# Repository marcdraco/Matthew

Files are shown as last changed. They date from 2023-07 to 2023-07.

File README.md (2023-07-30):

# Matthew
High-performance headphone amplifier based on the NE5532DR

This is, I hope the last main revision for this project (third one is a charm) after I found I'd specificied the wrong value on the JLCPCB ordering page resulting in 100K resistors being replaced by 1 ohm ... and the Magic Smoke came without the genie... Oh well. This is why I ask everyone to wait until I've gotten final boards back and tested them before you spend your money on my mistakes. I wish I never made a mistake but you know, it's how we learn.

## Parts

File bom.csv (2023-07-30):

Designator | Footprint | Quantity | Value | LCSC Part #
C101, C102, C103, C104 | C_Elec_10x10.2 | 4 | 1000u | C3359
C105, C106, C107, C108, C109, C110, C111, C112 | 0603 | 8 | 100n | C14663
C113, C114 | 1206 | 2 | 22u | C12891
C115, C116 | C_Elec_8x10.2 | 2 | 470U | C2827943
J1, J102 | PinHeader_1x03_P2.54mm_Vertical | 2 | Conn_01x03 | DNP
J104 | PinHeader_1x02_P2.54mm_Vertical | 1 | Socket_01x02 | DNP
R101, R102, R103, R104, R105, R106, R107, R108, R109, R110, R111, R112, R113, R114, R115, R116 | 0805 | 16 | 10R | C17415
R117, R118, R119, R120 | 0603 | 4 | 100K | C25803
U101, U102, U103, U104, U105, U106, U107, U108, U109 | SOIC-8_3.9x4.9mm_P1.27mm | 9 | NE5532 | C7426

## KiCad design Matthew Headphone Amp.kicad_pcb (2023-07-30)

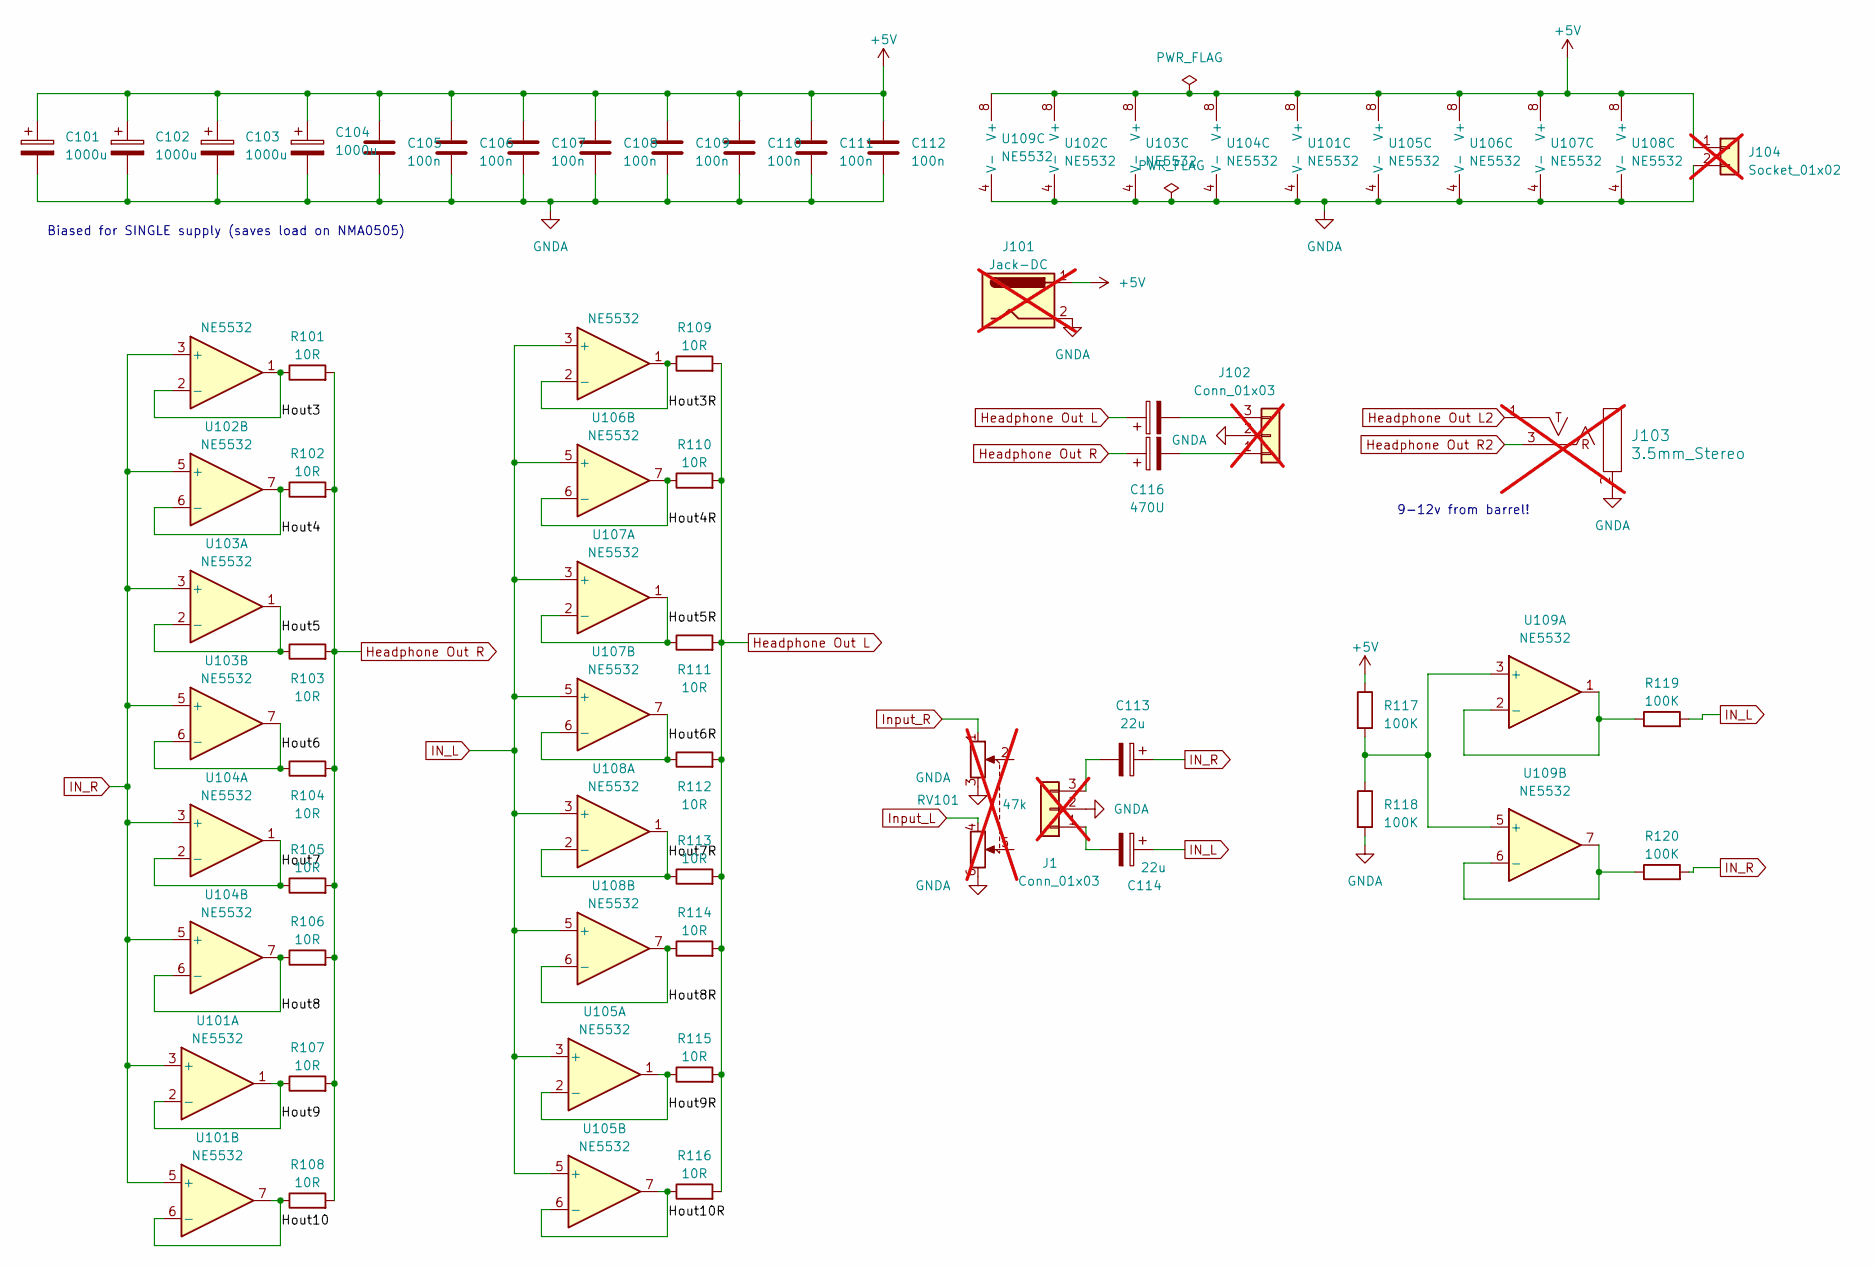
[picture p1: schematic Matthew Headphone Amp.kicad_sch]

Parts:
C101, C102, C103, C104: 1000u; C_Elec_10x10.2; MPN C3359
C105, C106, C107, C108, C109, C110, C111, C112: 100n; C_0603_1608Metric; MPN C14663
C113: 22u; C_1206_3216Metric; MPN C12891
C114: 22u; C_1206_3216Metric; MPN C12891; JLCPCBPart# C1289
C115, C116: 470U; C_Elec_8x10.2; MPN C2827943
J1, J102: Conn_01x03; PinHeader_1x03_P2.54mm_Vertical; Part Number 1-0301FBV0T; not fitted
J101: Jack-DC; PinHeader_1x02_P2.54mm_Vertical; not fitted
J103: 3.5mm_Stereo; EighthInch_Stereo_PJ366ST; Part Number WQP-WQP419GR; not fitted
J104: Socket_01x02; PinHeader_1x02_P2.54mm_Vertical; Part Number ?; not fitted
R101, R102, R103, R104, R105, R106, R107, R108, R109, R110, R111, R112, R113, R114, R115, R116: 10R; R_0805_2012Metric; MPN C17415
R117, R118, R119, R120: 100K; R_0603_1608Metric; MPN C25803
RV101: 47k; not fitted
U101, U102, U103, U104, U105, U106, U107, U108, U109: NE5532; SOIC-8_3.9x4.9mm_P1.27mm; MPN C7426

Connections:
+5V: C101.1, C102.1, C103.1, C104.1, C105.1, C106.1, C107.1, C108.1, C109.1, C110.1, C111.1, C112.1, J101.1, J104.1, R117.1, U101.8 (V+), U102.8 (V+), U103.8 (V+), U104.8 (V+), U105.8 (V+), U106.8 (V+), U107.8 (V+), U108.8 (V+), U109.8 (V+)
/Hout3: R101.1, U102.1, U102.2 (-)
/Hout3R: R109.1, U106.1, U106.2 (-)
/Hout4: R102.1, U102.6 (-), U102.7
/Hout4R: R110.1, U106.6 (-), U106.7
/Hout5: R103.1, U103.1, U103.2 (-)
/Hout5R: R111.1, U107.1, U107.2 (-)
/Hout6: R104.1, U103.6 (-), U103.7
/Hout6R: R112.1, U107.6 (-), U107.7
/Hout7: R105.1, U104.1, U104.2 (-)
/Hout7R: R113.1, U108.1, U108.2 (-)
/Hout8: R106.1, U104.6 (-), U104.7
/Hout8R: R114.1, U108.6 (-), U108.7
/Hout9: R107.1, U101.1, U101.2 (-)
/Hout9R: R115.1, U105.1, U105.2 (-)
/Hout10: R108.1, U101.6 (-), U101.7
/Hout10R: R116.1, U105.6 (-), U105.7
GNDA: C101.2, C102.2, C103.2, C104.2, C105.2, C106.2, C107.2, C108.2, C109.2, C110.2, C111.2, C112.2, J1.2, J101.2, J102.2, J103.2 (SHEILD), J104.2, R118.2, RV101.3, RV101.6, U101.4 (V-), U102.4 (V-), U103.4 (V-), U104.4 (V-), U105.4 (V-), U106.4 (V-), U107.4 (V-), U108.4 (V-), U109.4 (V-)
Headphone Out L: C115.1, R109.2, R110.2, R111.2, R112.2, R113.2, R114.2, R115.2, R116.2
Headphone Out R: C116.1, R101.2, R102.2, R103.2, R104.2, R105.2, R106.2, R107.2, R108.2
IN_L: C114.1, R119.2, U105.3 (+), U105.5 (+), U106.3 (+), U106.5 (+), U107.3 (+), U107.5 (+), U108.3 (+), U108.5 (+)
IN_R: C113.1, R120.2, U101.3 (+), U101.5 (+), U102.3 (+), U102.5 (+), U103.3 (+), U103.5 (+), U104.3 (+), U104.5 (+)
unnamed: C114.2, J1.1
unnamed: C113.2, J1.3
unnamed: C116.2, J102.1
unnamed: C115.2, J102.3
unnamed: R117.2, R118.1, U109.3 (+), U109.5 (+)
unnamed: R119.1, U109.1, U109.2 (-)
unnamed: R120.1, U109.6 (-), U109.7

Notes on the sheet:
Biased for SINGLE supply (saves load on NMA0505)
9-12v from barrel!

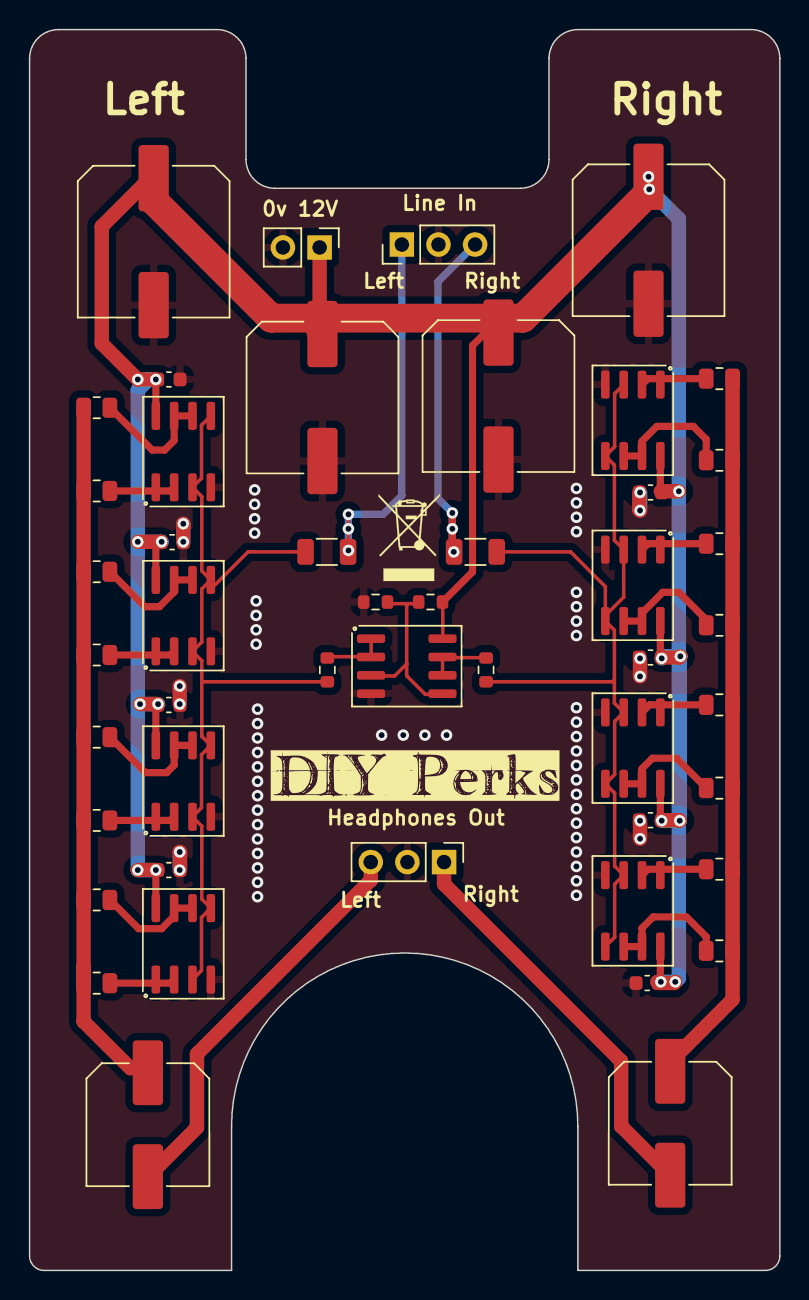
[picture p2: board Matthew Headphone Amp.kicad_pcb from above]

Board: 2 copper layers, 52.0 x 86.0 mm, 48 parts (0 on the bottom side), 29 nets.
